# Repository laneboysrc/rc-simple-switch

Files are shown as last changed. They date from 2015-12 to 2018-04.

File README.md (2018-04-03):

# Simple switch for RC systems

The LANE Boys RC Simple Switch allows you to turn an electronic load mounted to your RC model on or off remotely through your transmitter.

For example you can turn LEDs powered via the receiver on and off, or a light strip powered from an external battery.

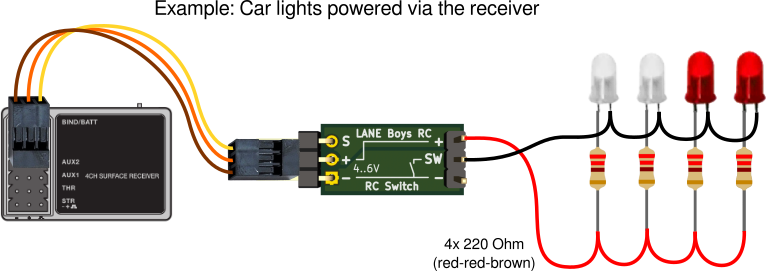
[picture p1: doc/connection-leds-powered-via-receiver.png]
Connection diagram 4 LEDs


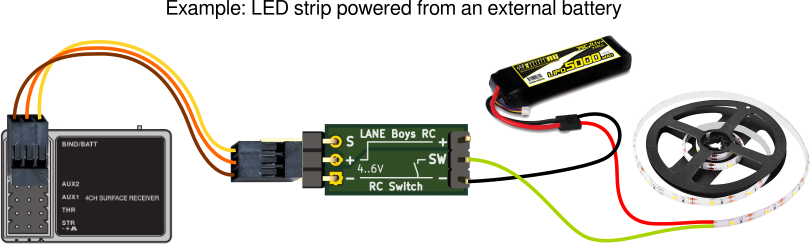
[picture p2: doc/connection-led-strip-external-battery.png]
Connection diagram LED strip


The circuit board measures 20 x 10mm (0.8 x 0.4"), excluding connectors. The switch can handle loads of up to 2A @ 20V.

Servo pulses range from 1 .. 2ms, with 1.5ms being defined as center position.
The switch turns on when the incoming servo pulse is greater than 1.6ms, and turns off again when the servo pulse becomes less than 1.4ms.
This hysteresis makes it suitable for use with both switches and analog controls.

Power consumption of the RC switch itself (without load) is about 4mA.

You can obtain a ready-to-use built-up RC simple switch from [laneboysrc@gmail.com](mailto:laneboysrc@gmail.com), or build one yourself using the information provided here.

# Electronics

There are two variants provided, both with identical size and functionality:

### STC STC15W104 variant

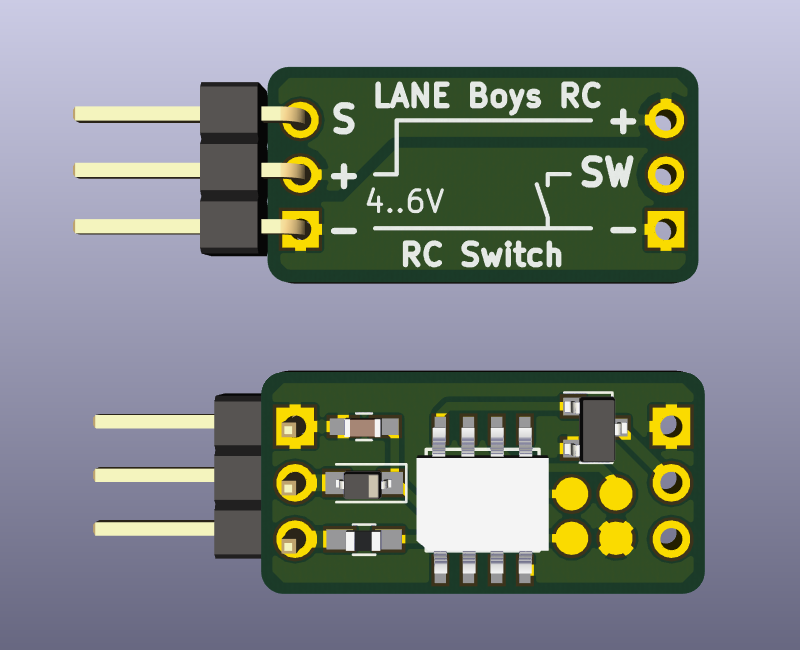
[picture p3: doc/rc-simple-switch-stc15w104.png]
STC15W104 PCB


### Microchip PIC10F200 variant

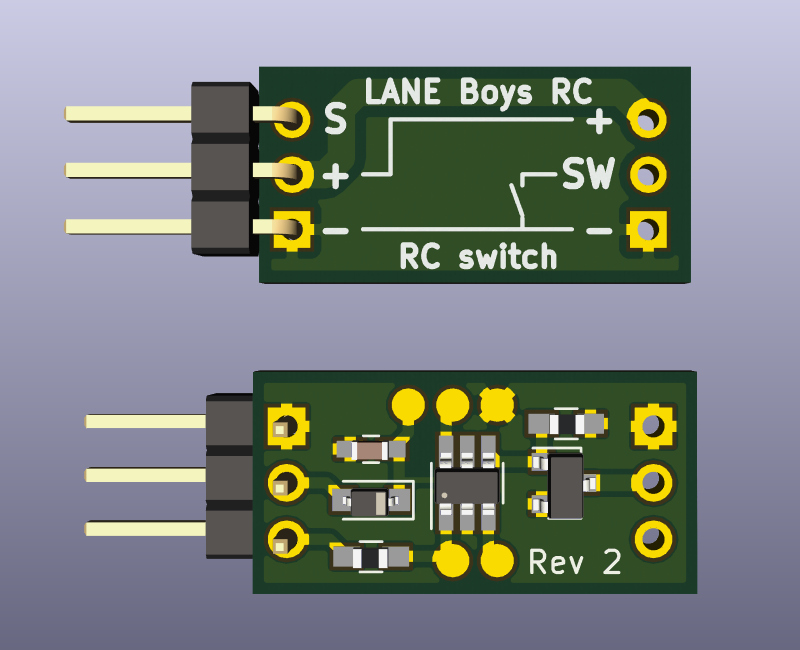
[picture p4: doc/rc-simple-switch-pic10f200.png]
PIC10F200 PCB


Which one you choose depends on how easy it is for you to get the respective chips, your familiarity with them, and whether you already have respective programming tools.

The STC15W104 can be programmed using a simple USB-to-serial converter, or a Raspberry Pi (or similar SBC with a serial port). The STC15W104 originates from China and can be found on eBay and Aliexpress.

The PIC10F200 version requires a Microchip Pickit for programming, which can be quite an investment. The PIC10F200 can be obtained from major electronics distributors like Digikey, Element14, Mouser ...

Both chips come in DIP package versions so you can easily build the hardware on a prototyping board.

There is also a PCB for SMD components available for both variants. Gerber files are provided so you can order PCBs from you favorite manufacturer.

# Firmware

Pre-compiled HEX files are supplied: [PIC10F200 firmware](rc-simple-switch-pic10f200.hex), [STC15W104 firmware](rc-simple-switch-stc15w104.hex)

The firmware for both variants can be compiled with the [SDCC compiler](http://sdcc.sourceforge.net/).

For programming the PIC10F200 variant please consult Microchip for the required tools and software.

For programming the STC15W104 variant we recommend the [STCGAL](https://github.com/grigorig/stcgal), an open source Python program.

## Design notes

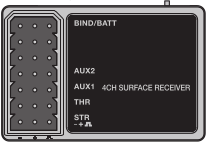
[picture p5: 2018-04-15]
doc/receiver.png

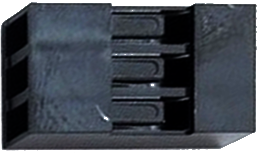
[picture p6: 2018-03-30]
doc/dupont-3p.png

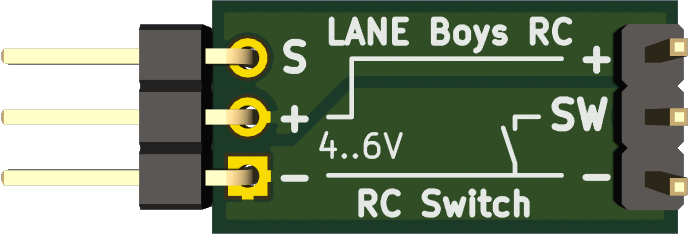
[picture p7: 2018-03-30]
doc/rc-simple-switch.png

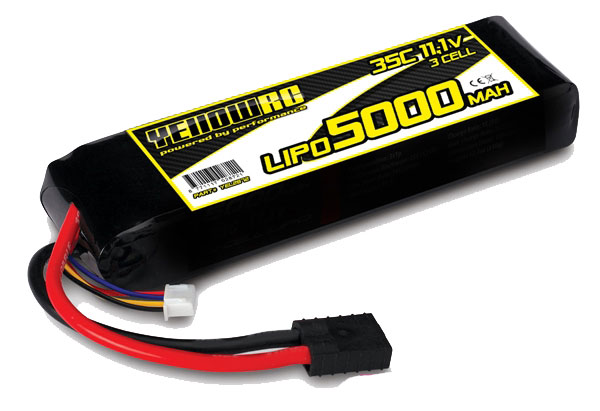
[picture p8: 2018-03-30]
doc/lipo.jpg

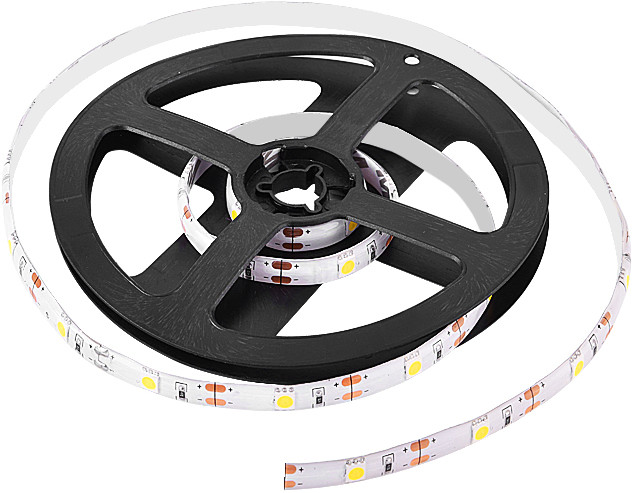
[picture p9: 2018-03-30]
doc/led-strip.jpg

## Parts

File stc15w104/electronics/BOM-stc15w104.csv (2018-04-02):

Reference | Value | Footprint | Datasheet
D1 | 1N4148 | Diodes_SMD:D_SOD-323_HandSoldering
J1 | IN | Pin_Headers:Pin_Header_Angled_1x03_Pitch2.54mm
J2 | SW | Pin_Headers:Pin_Header_Straight_1x03_Pitch2.54mm
TP3 | TX | Measurement_Points:Measurement_Point_Round-SMD-Pad_Small
TP4 | RX | Measurement_Points:Measurement_Point_Round-SMD-Pad_Small
R1 | 1k | Resistors_SMD:R_0603_HandSoldering
Q1 | PMV30UN | TO_SOT_Packages_SMD:SOT-23
TP2 | GND | Measurement_Points:Measurement_Point_Round-SMD-Pad_Small
TP1 | VCC | Measurement_Points:Measurement_Point_Round-SMD-Pad_Small
U1 | STC15W104 | SMD_Packages:SOIC-8-N
C1 | 1u | Capacitors_SMD:C_0603_HandSoldering

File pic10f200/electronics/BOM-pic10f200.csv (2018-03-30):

Source: | /home/laneboysrc/projects/rc-simple-switch/pic10f200/electronics/rc-simple-switch.sch
Date: | Fri 30 Mar 2018 09:07:37 AM
Tool: | Eeschema 4.0.7-e2-6376~58~ubuntu16.04.1
Component Count: | 13
Ref | Value | Footprint | Datasheet | Manufacturer | Vendor
C1 | 1u | Capacitors_SMD:C_0603_HandSoldering
D1 | 1N4148 | Diodes_SMD:D_SOD-323_HandSoldering
K1 | IN | Pin_Headers:Pin_Header_Angled_1x03_Pitch2.54mm
K2 | SW | Pin_Headers:Pin_Header_Straight_1x03_Pitch2.54mm
Q1 | PMV30UN | TO_SOT_Packages_SMD:SOT-23 |  | NXP
R1 | 1k | Resistors_SMD:R_0603_HandSoldering
R2 | 10k | Resistors_SMD:R_0603_HandSoldering
U1 | PIC10F200 | TO_SOT_Packages_SMD:SOT-23-6_Handsoldering |  | Microchip

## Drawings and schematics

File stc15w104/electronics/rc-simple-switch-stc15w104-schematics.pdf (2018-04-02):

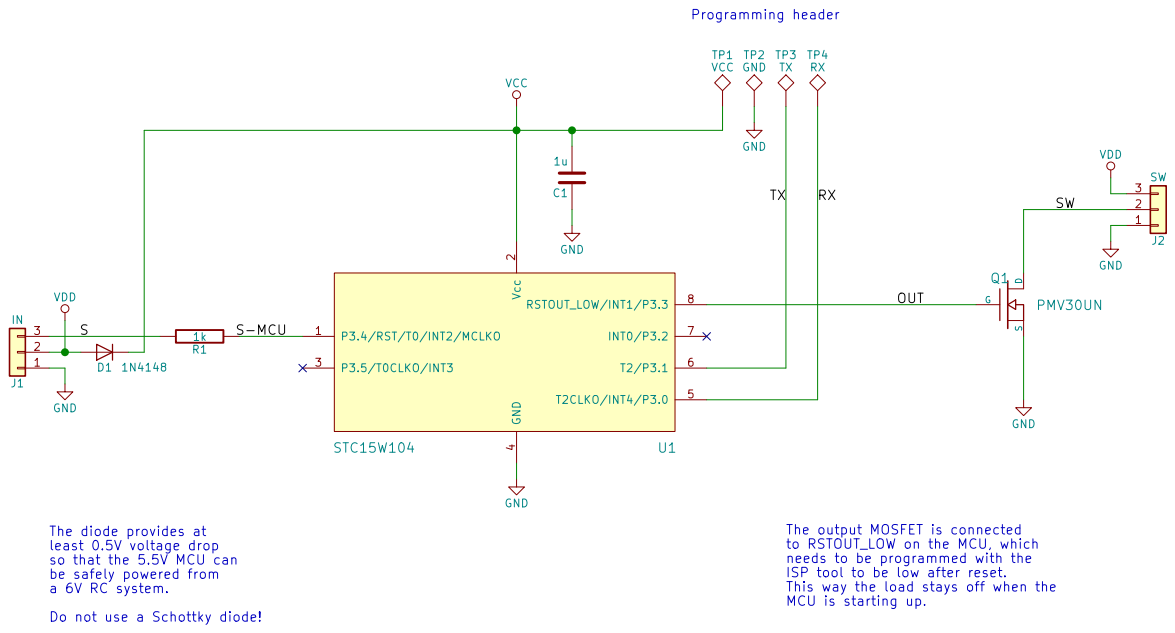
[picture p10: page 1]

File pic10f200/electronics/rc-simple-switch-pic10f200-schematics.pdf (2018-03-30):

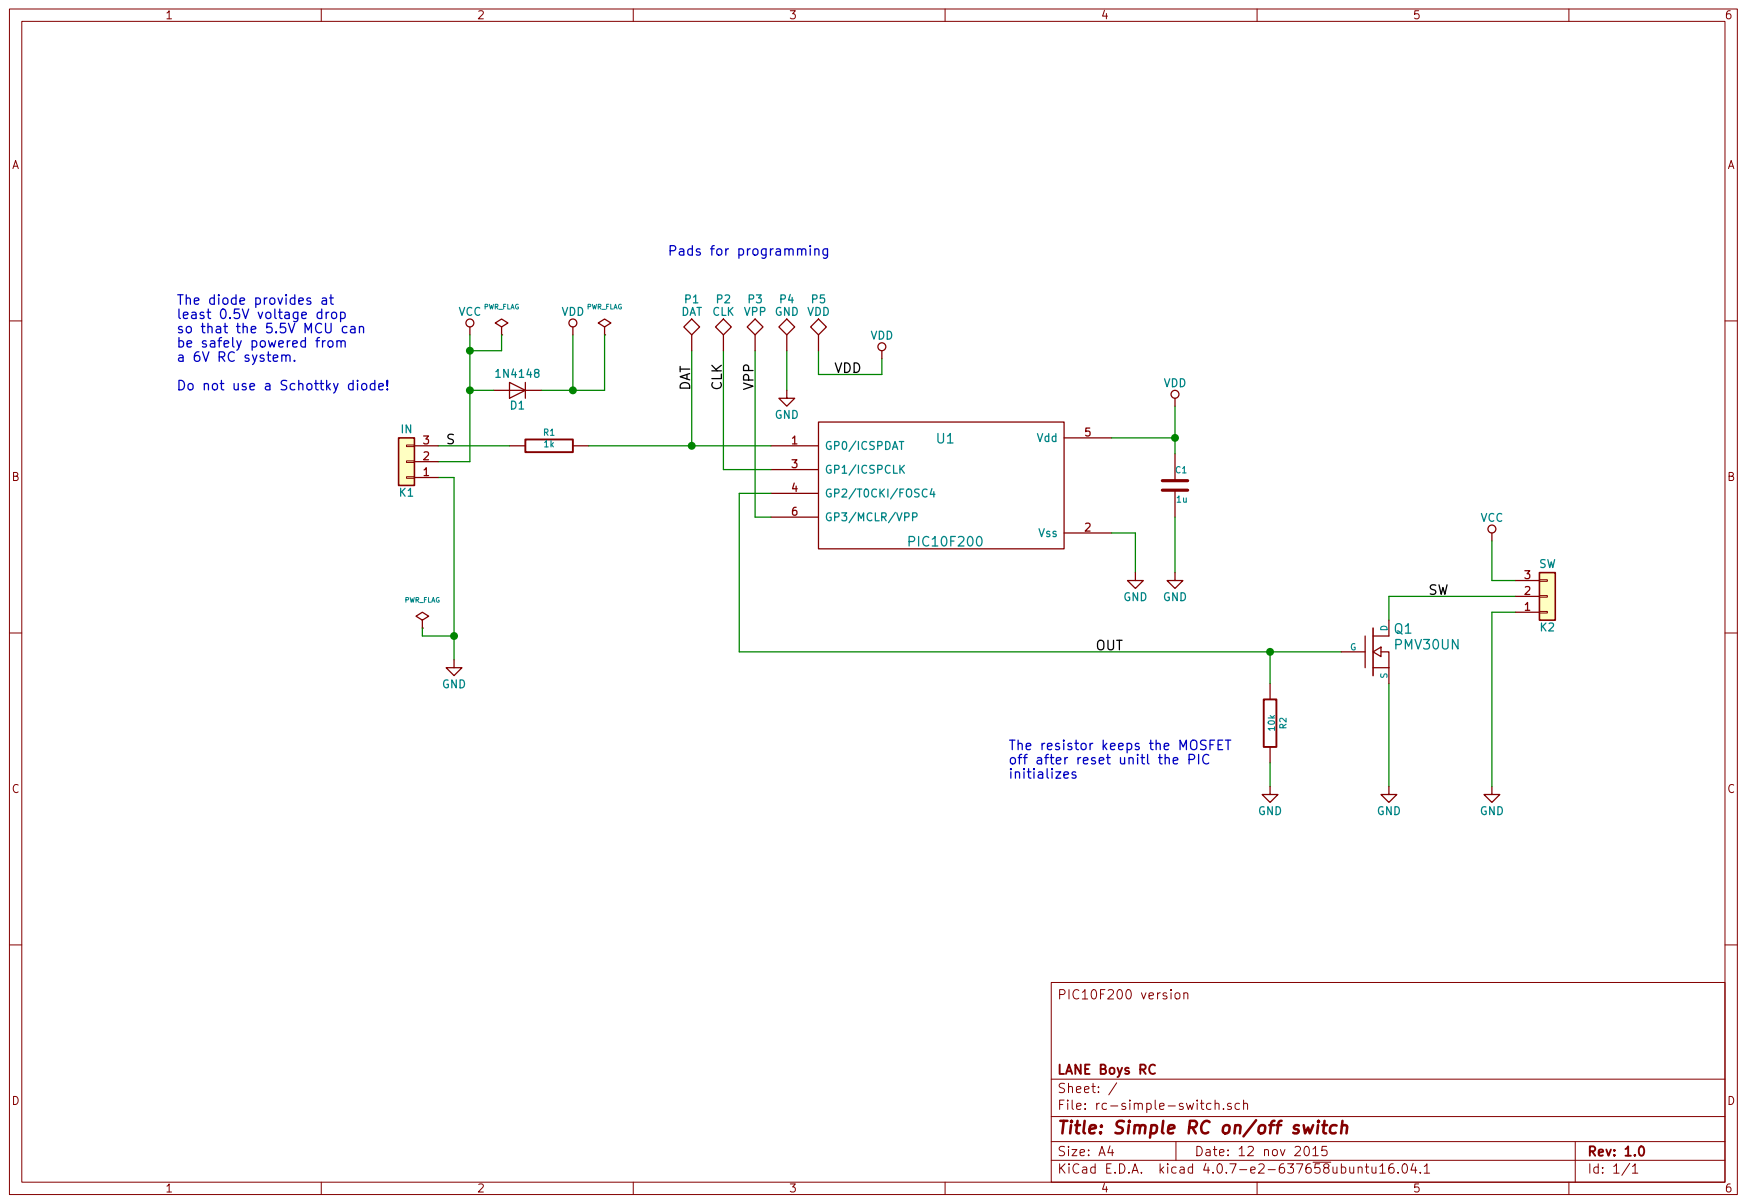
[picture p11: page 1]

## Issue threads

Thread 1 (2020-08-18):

Through-hole parts

gbraad, 2020-08-18:
All the parts are easy to replace with through hole components. What would be the suggested alternative for the PMV30UN?

laneboysrc, 2020-08-18:
I don't have any experience with through-hole parts.
Basically what you need is a MOSFET that is "logic-level", i.e. it has a very low Vgs threshold.
An example that seems to fit the spec: Fairchild FQP30N06L,

gbraad, 2020-08-18:
Thanks, so either a FQP30N06L or IRLB8721 will do, driven from the gate.

Closed 2020-08-18.

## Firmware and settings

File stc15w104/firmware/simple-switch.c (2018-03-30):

#include "stdint.h"
#include "stdbool.h"

#include "stc15x10x.h"

#define TIMER_RESOLUTION 16  // Timer0 tick every 16us

// The output MOSFET is connected to RSTOUT_LOW (P3.3) on the MCU, which
// needs to be programmed with the ISP tool to be low after reset.
// This way the load stays off when the MCU is starting up.
#define SWITCH_OUT P33
#define SERVO_IN P34

#define TMR_TOO_LOW (600 / TIMER_RESOLUTION)
#define TMR_TOO_HIGH (2400 / TIMER_RESOLUTION)
#define TMR_OFF (1400 / TIMER_RESOLUTION)
#define TMR_ON (1600 / TIMER_RESOLUTION)

static void output_is_off()
{
    SWITCH_OUT = 0;

    while (1) {
        // Wait for servo pulse being low
        while (SERVO_IN);

        // Wait for servo pulse rising edge
        while (!SERVO_IN);

        // Start measuring the servo pulse width
        TL0 = 0;

        while(1) {
            // Wait for servo pulse falling edge
            if (!SERVO_IN) {
                // Pulse longer than 1600us? -> Turn on!
                if (TL0 > TMR_ON) {
                    // Exit this function!
                    return;
                }
                // ... all other pulse lengths: ignore
                break;
            }

            if (TL0 > TMR_TOO_HIGH) {
                // Pulse longer than 2400us? -> Ignore
                break;
            }
        }
    }
}

static void output_is_on()
{
    SWITCH_OUT = 1;

    while (1) {
        // Wait for servo pulse being low
        while (SERVO_IN);

        // Wait for servo pulse rising edge
        while (!SERVO_IN);

        // Start measuring the servo pulse width
        TL0 = 0;

        while(1) {
            // Wait for servo pulse falling edge
            if (!SERVO_IN) {
                // Pulse shorter than 600us? -> Ignore
                if (TL0 < TMR_TOO_LOW) {
                    break;
                }
                // Pulse shorter than 1400us? -> Turn off!
                if (TL0 < TMR_OFF) {
                    // Exit this function!
                    return;
                }
                // ... all other pulse lengths: ignore
                break;
            }

            if (TL0 > TMR_TOO_HIGH) {
                // Pulse longer than 2400us? -> Ignore
                break;
            }
        }
    }
}

//----------------------------------------------------------------------------
void main()
{
    P3M0 = 1 << 3;  // Push-pull output on P3.3
    P3M1 = 0x00;

    // The programmer sets the clock to 6 MHz. We divide that by 8, and then
    // run the timer sysclock/12.
    // 6 MHz / (8 * 12) = 16 us per tick

    PCON2 = 0x03;   // Master clock frequency/8

    TMOD = 0x02;    // Timer0 Mode 2 (8 bit mode)
    AUXR = 0x00;    // The clock source of Timer 0 is SYSclk/12
    TH0 = 0;
    TR0 = 1;        // Enable Timer0

    while (1) {
        output_is_off();
        output_is_on();
    }
}

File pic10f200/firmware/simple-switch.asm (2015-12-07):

;******************************************************************************
;
;   simple-switch.asm
;
;******************************************************************************
;
;   Author:         Werner Lane
;   E-mail:         laneboysrc@gmail.com
;
;******************************************************************************
    TITLE       RC Simple Switch
    LIST        r=dec
    RADIX       dec

    PROCESSOR   PIC10F200
    #include    <p10f200.inc>
    __CONFIG     _WDTE_OFF & _MCLRE_OFF & _CP_OFF



;******************************************************************************
;* CONSTANT DEFINITIONS
;******************************************************************************
SERVO_IN            equ     0   ; Servo input is GP0
OUTPUT_PIN          equ     2   ; Switch output is GP2

TIMER_RESOLUTION    equ     32  ; Timer runs at Fosc/4 / 32 => 1 tick every 32us

TMR_TOO_LOW         equ     600 / TIMER_RESOLUTION
TMR_TOO_HIGH        equ     2400 / TIMER_RESOLUTION
TMR_OFF             equ     1400 / TIMER_RESOLUTION
TMR_ON              equ     1600 / TIMER_RESOLUTION



;******************************************************************************
;* VARIABLE DEFINITIONS
;******************************************************************************
.data UDATA

pulse_width         res 1



;******************************************************************************
; Reset vector
;******************************************************************************
.code_reset CODE    0x000


;******************************************************************************
; Initialization
;******************************************************************************
Init
    movwf   OSCCAL      ; The last address in the program memory contains
                        ; the factory set OSCCAL value with an movlw
                        ; instruction. We put this value into OSCCAL to get
                        ; a precise clock,
                        ; See data sheet section 9.2.2 INTERNAL 4 MHz OSCILLATOR

    movlw   b'10000100' ; Wakeup on pin change disables, weak pull-ups enabled,
                        ; Timer0 clock source Fosc/4, Prescaler assigned to
                        ; Timer0, Prescaler 1:32 (= 32us per tick @ 4 MHz)
    option

    movlw   b'00000001' ; GPIO 0 input, all others output
    tris    6

    clrf    GPIO        ; Set all ports to low


;**********************************************************************
; Main program
;**********************************************************************
Main_loop

output_is_off
    ; Wait for servo pulse being low
    btfsc   GPIO, SERVO_IN
    goto    $-1

    ; Wait for servo pulse rising edge
    btfss   GPIO, SERVO_IN
    goto    $-1

    ; Start measuring the servo pulse width
    clrf    TMR0

    ; Wait for servo pulse falling edge
off_wait_for_falling
    movlw   TMR_TOO_HIGH
    subwf   TMR0, W
    bc      output_is_off           ; Pulse longer than 2400us? -> Ignore
    btfsc   GPIO, SERVO_IN
    goto    off_wait_for_falling

    movf    TMR0, W
    movwf   pulse_width
    movlw   TMR_TOO_LOW             ; Pulse shorter than 600us? -> Ignore
    subwf   pulse_width, w
    bnc     output_is_off
    movlw   TMR_ON                  ; Pulse longer than 1600us? -> Turn on!
    subwf   pulse_width, w
    bnc     output_is_off

    bsf     GPIO, OUTPUT_PIN



output_is_on
    ; Wait for servo pulse being low
    btfsc   GPIO, SERVO_IN
    goto    $-1

    ; Wait for servo pulse rising edge
    btfss   GPIO, SERVO_IN
    goto    $-1

    ; Start measuring the servo pulse width
    clrf    TMR0

    ; Wait for servo pulse falling edge
on_wait_for_falling
    movlw   TMR_TOO_HIGH
    subwf   TMR0, W
    bc      output_is_on            ; Pulse longer than 2400us? -> Ignore
    btfsc   GPIO, SERVO_IN
    goto    on_wait_for_falling

    movf    TMR0, W
    movwf   pulse_width
    movlw   TMR_TOO_LOW             ; Pulse shorter than 600us? -> Ignore
    subwf   pulse_width, w
    bnc     output_is_on
    movlw   TMR_OFF                 ; Pulse shorter than 1400us? -> Turn off!
    subwf   pulse_width, w
    bc      output_is_on

    bcf     GPIO, OUTPUT_PIN

    goto    Main_loop


;**********************************************************************
    END     ; Directive 'end of program'

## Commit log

2015-11-10 Implement pulse too large detection
    [simple-switch.asm]
2015-11-11 Fix ge/le comparison with timer
    [simple-switch.asm]
2015-11-11 Add KiCAD board and schematics draft
    [rc-simple-switch.kicad_pcb, rc-simple-switch.sch]
2015-11-11 Tweak the PCB
    [rc-simple-switch.kicad_pcb, rc-simple-switch.sch]
2015-11-12 Make the board smaller and re-orient output connector
    [rc-simple-switch.kicad_pcb, rc-simple-switch.sch]
2015-11-14 Tweak display
    [rc-simple-switch.kicad_pcb]
2015-12-02 Make the switch work with 10LF322 for testing
2018-03-27 Re-design layout and move to latest Kicad version
    [rc-simple-switch.kicad_pcb, rc-simple-switch.sch]
2018-03-28 Finish PCB re-layout
    [rc-simple-switch.kicad_pcb, rc-simple-switch.sch]
2018-03-28 Add PCB revision
    [rc-simple-switch.kicad_pcb]
2018-03-28 Move PIC10F200 version into subdirectory to prepare for STC version
    [rc-simple-switch.kicad_pcb, rc-simple-switch.sch]
2018-03-28 Add STC schematics
    [rc-simple-switch-stc.kicad_pcb, rc-simple-switch-stc.sch]
2018-03-28 Shrink the STC board by 2 mm
    [rc-simple-switch-stc.kicad_pcb]
2018-03-28 Make STC PCB 20x10, same as PIC10F PCB
    [rc-simple-switch-stc.kicad_pcb]
2018-03-29 Soldermask clearance set to 7mil
    [rc-simple-switch-stc.kicad_pcb, rc-simple-switch.kicad_pcb]
2018-03-29 Fix broken file caused by merge
    [rc-simple-switch-stc.kicad_pcb]
2018-03-29 Add STC firmware
    [rc-simple-switch-stc.sch]
2018-03-30 Fix the schematics
    [rc-simple-switch.kicad_pcb, rc-simple-switch.sch]
2018-03-30 Improve STC schematics
    [rc-simple-switch-stc.kicad_pcb, rc-simple-switch-stc.sch]
2018-03-30 Add PDF schematics
2018-03-30 Add BOM files
    [BOM-pic10f200.csv, BOM-stc15w104.csv]
2018-03-30 Add Gerber files
2018-03-30 Update drawings with Dupont style connector
2018-03-30 Update documentation
    [rc-simple-switch-stc.kicad_pcb, rc-simple-switch.kicad_pcb]
2018-04-02 Round-off the corners
    [rc-simple-switch-stc.kicad_pcb]
2018-04-02 Update BOM, schematics and Gerber
    [BOM-stc15w104.csv]
2018-04-03 Re-make board images
    [rc-simple-switch-stc.kicad_pcb, rc-simple-switch.kicad_pcb]
2018-04-04 Add low voltage reset
